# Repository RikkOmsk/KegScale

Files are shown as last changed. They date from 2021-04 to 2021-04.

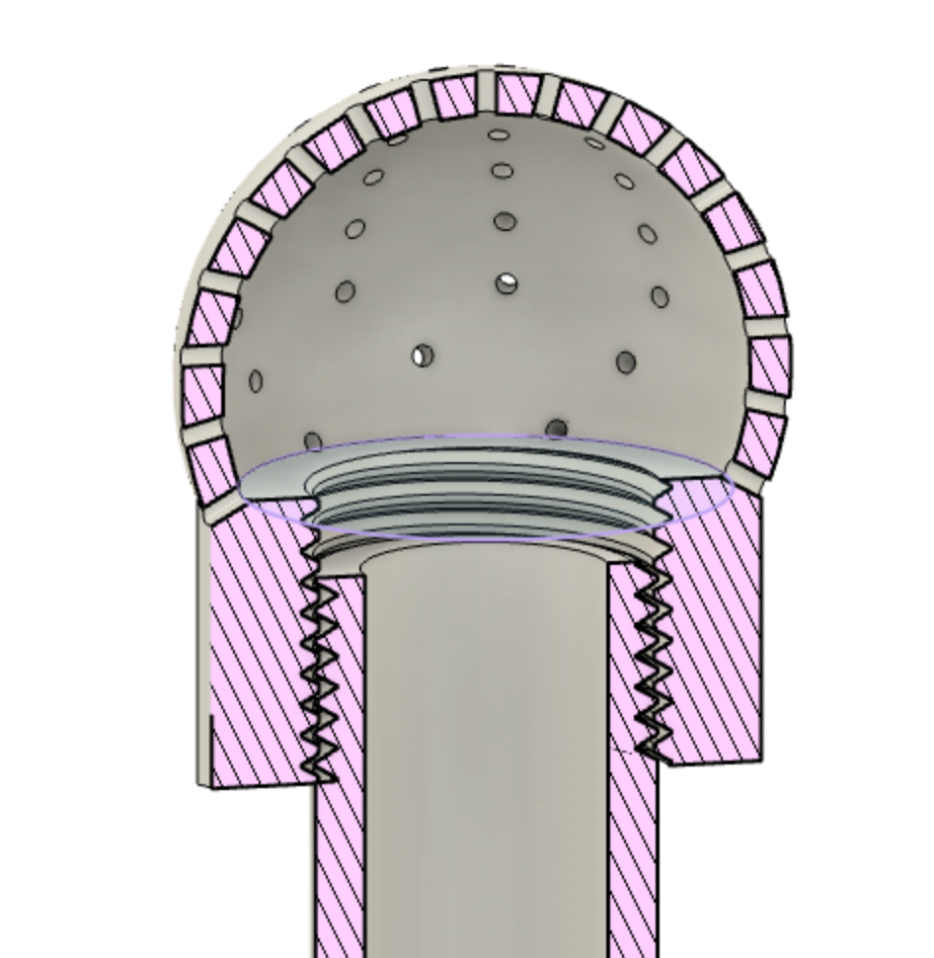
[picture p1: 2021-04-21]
washKeg_0.2/img/screen3.png

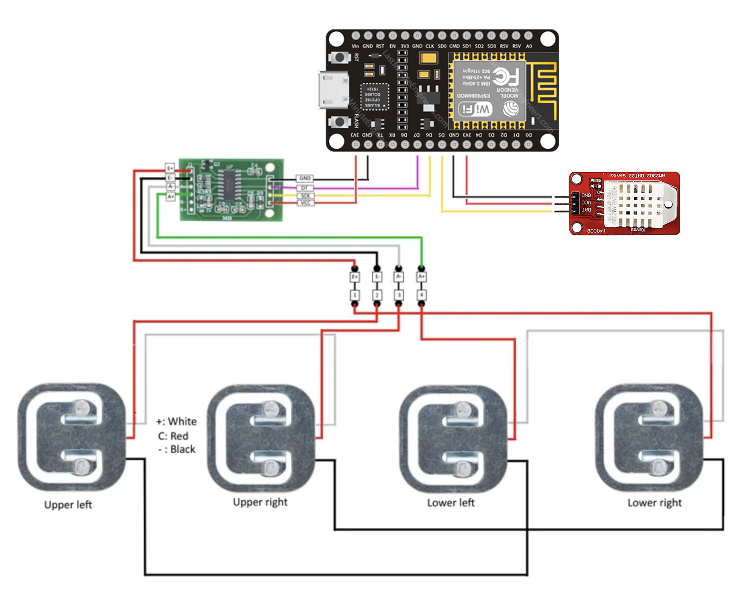
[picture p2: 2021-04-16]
scheme/main.jpg

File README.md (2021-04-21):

# KegScale
Keg Scale

# Железо
Потребуются 
  1. ESP8266        https://aliexpress.ru/item/4000160133215.html
  2. AM2302 DHT22   https://aliexpress.ru/item/32759901711.html
  3. HX711          https://aliexpress.ru/item/1005002176327047.html

# Схема подключения
/scheme/main.jpg

# Прошивка под Arduino
/ESP8266/ESP8266_keg_v02.ino
Необходимо заменить все что под ***
 - auth key blynk
 - ssid wifi
 - pass wifi

# 3D модель для печати
/3dModel/print_01.stl - первая модель площадки. Печать с поддержками 40% заполнения
/3dModel/flexTop v1.stl - первая модель площадки. Флекс резиновое кольцо сверху

/3dModel/print_02.stl - вторая модель площадки
/3dModel/log02_im1.png - список изменений
/3dModel/log02_im2.png - список изменений
/3dModel/log02_im3.png - список изменений

Список изменений v02: 
0. Печататься деталь будет вверх ногами.
1. Сделал паз под провода. Как оказалось, тензодатчики сложно установить без этого паза.
2. Убрал держатели для тензодатчиков. Паз ровно под размер датчиков и встает туда с усилием. Держатели мешали установке детчиков
3. Под NodeMCU дал еще 2 мм прострнаства. Сам ESP находится под смещенем на NodeMCU.
4. Увеличил размеры гнезда под microUSB. Не все штекера подошли.
5. Немного уменьшил вылеты площадки
6. Убрал паз под резиновое кольцо и поменяло форму кольца. Кольцо будет печататься в два слоя сразу же поверх площадки, что сделает изделие аккуратнее, резину тоньше и шире.
7. Сделал более пологий скос, чтобы при печати вверх ногами не потребовались поддержки.

# Калибровка 
Во время отладки необходимо настроить два поля:
int keg1_calibration_factor = -21020;   // Калибровочная значение, индивидуальное для каждой итоговой площадки
int keg1_offset_factor = -64200;        // 0 вес для площадки (сюда вставляем значение, который прилетает в keg1_raw при своем пустом весе)
1. Эти значения будут уникальны для каждого собранно устройства. Начинаем с keg1_offset_factor = в него устанавливаем значение, которое прийдет в keg1_raw при запуске устройства.
2. Далее нужно разместить заранее известный точный вес (например гирю либо бутылку с водой). К примеру вес гири 5кг. Далее мы смотрим на значение в консоли веса, который отображает ваше устройство. Если значение меньше либо больше, то необходимо поправить keg1_calibration_factor в меньшую либо большую сторону и щалитьпрошивку заново. Повторяйте до тех пор пока ваша площадка не будет отображать ровно 5 кг как и гиря.

# Настойка blynk
(будет позже)

# Бонус
washKeg_0.2 - Мойка для кег.
- washKeg_v0.2_top2.stl - 1 шт на кег 10л, вторую накручиваем если кег на 19.
- washKeg_v0.2_top1.stl 2шт.
- washKeg_v0.2_line1.stl 1шт. 
- washKeg_v0.2_line2.stl 2шт.
- washKeg_v0.2_dash.stl 1шт.
- washKeg_v0.2_stat.stl 4шт.

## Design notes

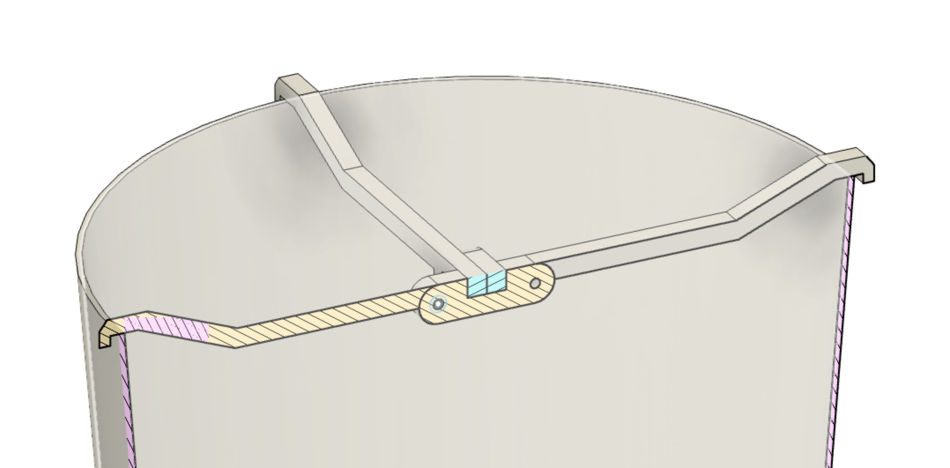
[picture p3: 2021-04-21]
washKeg_0.2/img/screen2.png

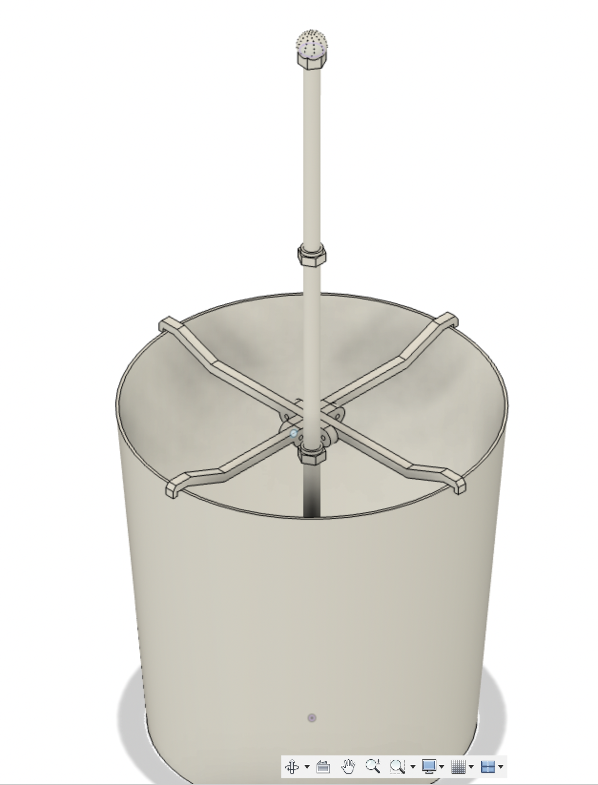
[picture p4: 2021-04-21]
washKeg_0.2/img/screen1.png

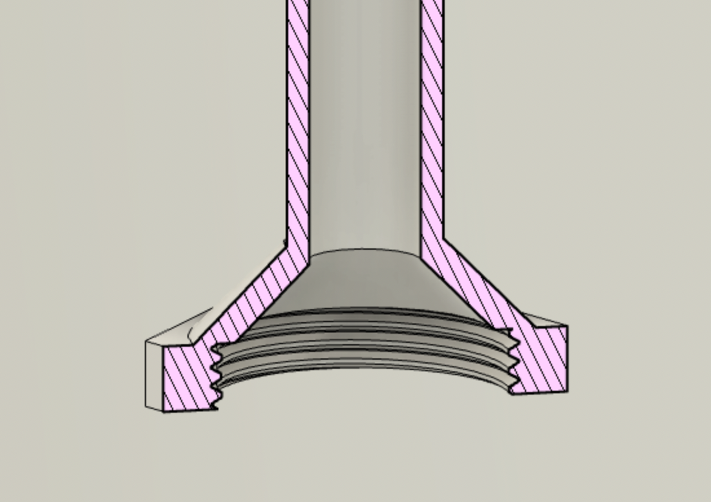
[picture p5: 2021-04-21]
washKeg_0.2/img/screen4.png

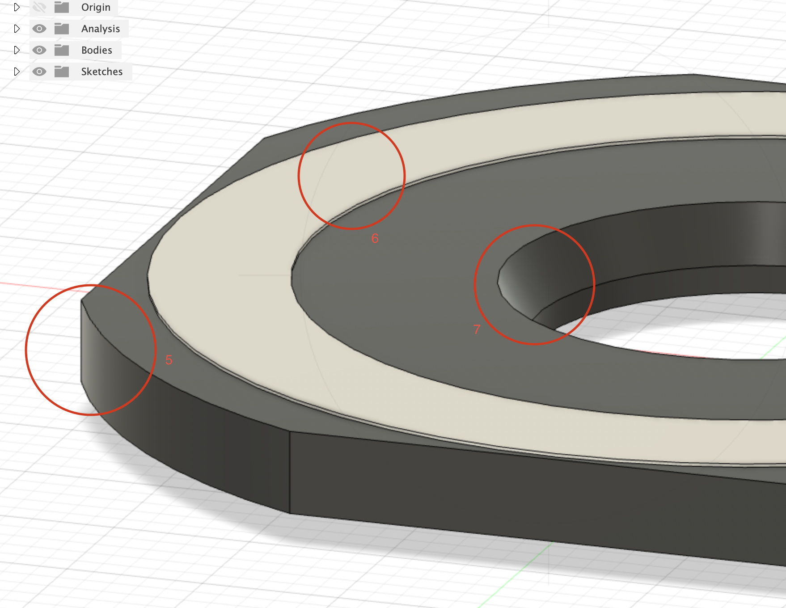
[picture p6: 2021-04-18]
3dModel/log02_im3.png

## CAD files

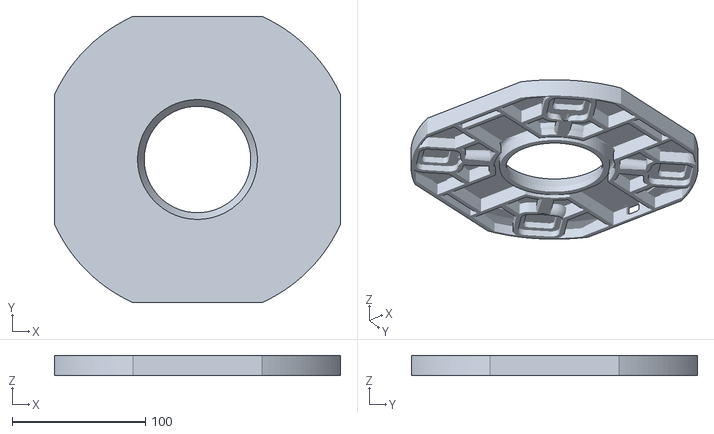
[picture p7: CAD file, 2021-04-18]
3dModel/print_02.stl
215.0 x 215.0 x 15.0

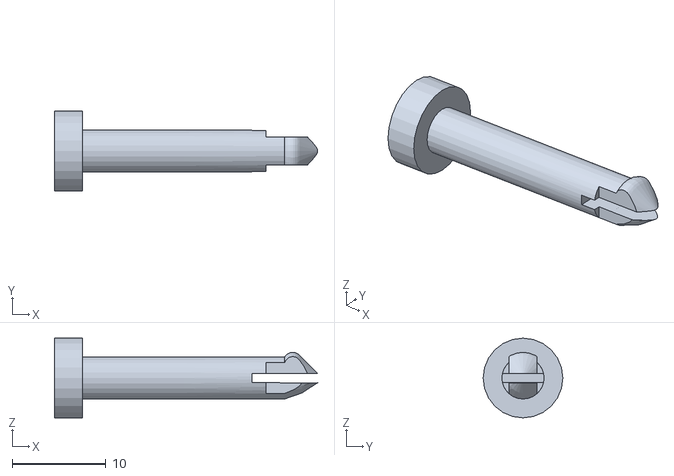
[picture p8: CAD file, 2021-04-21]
washKeg_0.2/model/washKeg_v0.2_stat.stl
28.0 x 8.49 x 8.49

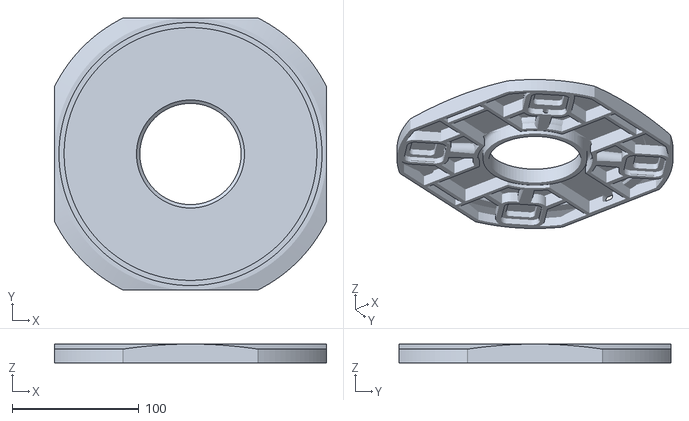
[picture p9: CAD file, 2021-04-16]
3dModel/print_01.stl
215.0 x 215.0 x 15.0

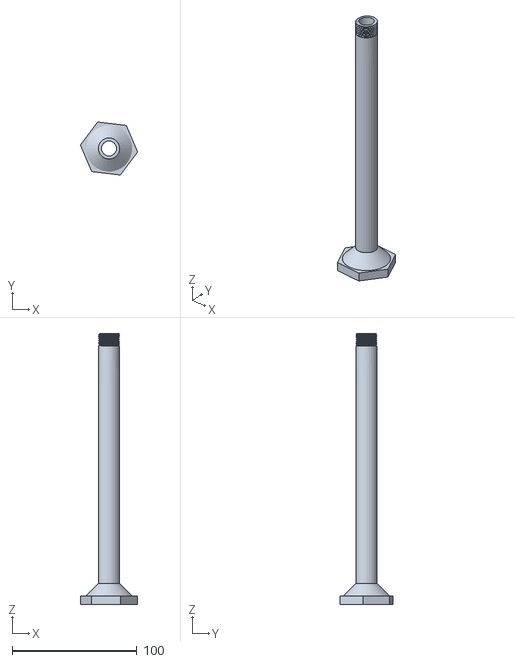
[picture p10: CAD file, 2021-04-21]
washKeg_0.2/model/washKeg_v0.2_line1.stl
45.9 x 42.5 x 217.0

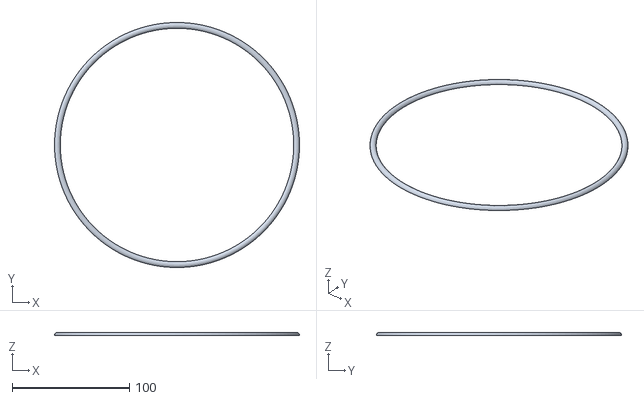
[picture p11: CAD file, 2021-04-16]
3dModel/flexTop v1.stl
208.7 x 208.8 x 2.95

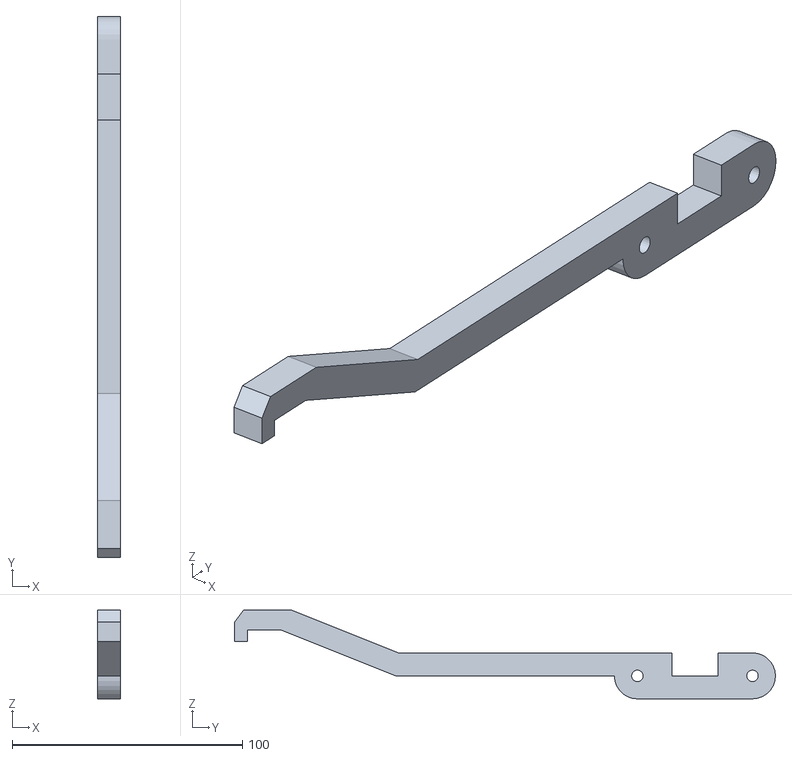
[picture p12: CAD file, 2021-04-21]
washKeg_0.2/model/washKeg_v0.2_top1.stl
10.0 x 235.0 x 38.6

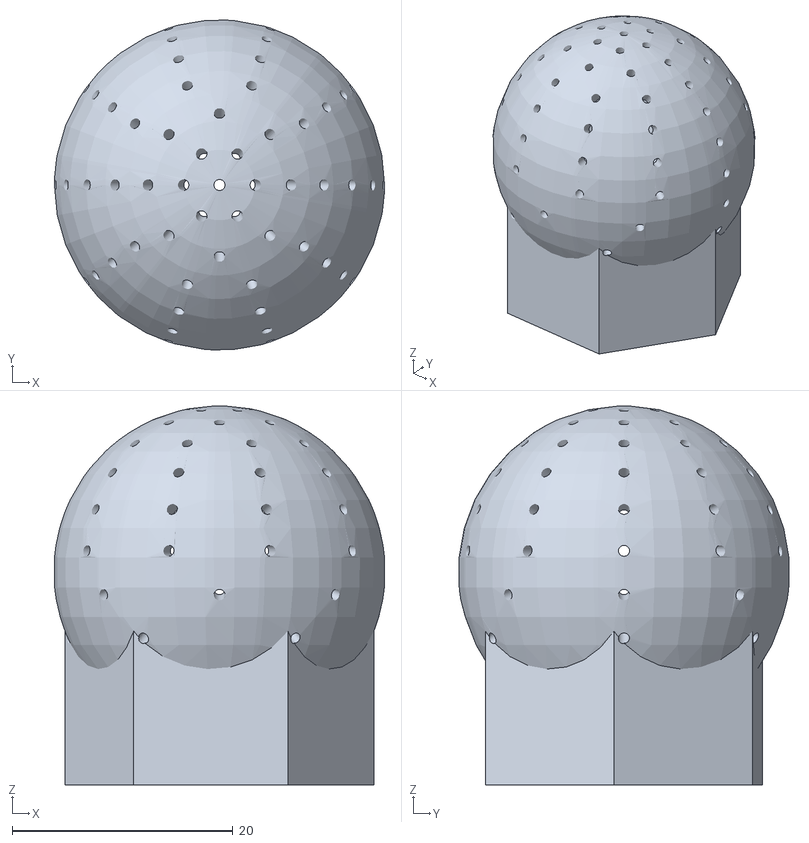
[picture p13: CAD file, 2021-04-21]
washKeg_0.2/model/washKeg_v0.2_dash.stl
29.9 x 29.9 x 34.3

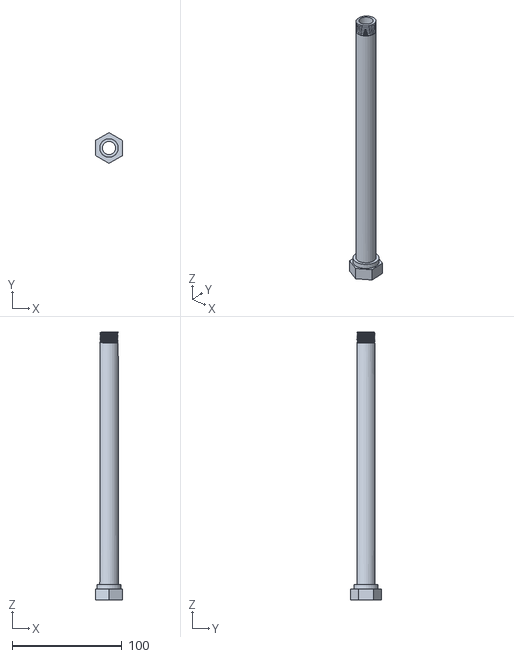
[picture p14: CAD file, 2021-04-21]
washKeg_0.2/model/washKeg_v0.2_line2.stl
24.3 x 28.0 x 244.0

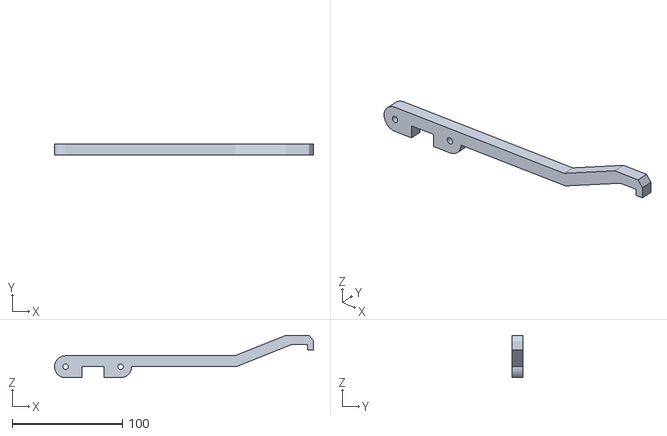
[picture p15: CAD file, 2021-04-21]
washKeg_0.2/model/washKeg_v0.2_top2.stl
235.0 x 10.0 x 38.5

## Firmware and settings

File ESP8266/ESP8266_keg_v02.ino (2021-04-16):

#include <HX711.h>
#include <DHT.h>
#include <DHT_U.h>


#define BLYNK_PRINT Serial
#include <ESP8266WiFi.h>
#include <BlynkSimpleEsp8266.h>


// You should get Auth Token in the Blynk App.
char auth[] = "*******";

// Your WiFi credentials.
char ssid[] = "*****";
char pass[] = "*****";

float beer_coef = 1.04; //1литр пива это 1.04кг

int keg1_calibration_factor = -21020;   // Калибровочная значение, индивидуальное для каждой итоговой площадки
int keg1_offset_factor = -64200;        // 0 вес для площадки (сюда вставляем значение, который прилетает в keg1_raw при своем пустом весе)
float keg1_keg_scale = 0.00;            // Вес пустого кега, размещенного на площадке
bool keg1_isNeedSetKegScale = false;
// Датчик веса
const int keg1_LOADCELL_DOUT_PIN = 13; 
const int keg1_LOADCELL_SCK_PIN = 12;
HX711 keg1_scale;

// датчик DHT
uint8_t DHTPin = D5; 
DHT dht(DHTPin, DHT22);
float temperature;
float humidity;

BlynkTimer timer;


BLYNK_WRITE(V42) { //получаем вес кега 1 с сервера
  float f_scale = param.asFloat();
  if (f_scale > 0){
    keg1_keg_scale = f_scale;
  }else{
    keg1_keg_scale = 0;
  }
}

BLYNK_WRITE(V43){ //получаем состояние кнопки 1 с сервера
  int intButtonPressed = param.asInt();
  if (intButtonPressed == 0) { //нажатие кнопки "сбросить вес" кег1
    Serial.println("Button is pressed.");
    Blynk.setProperty(V43, "label", "Ожидайте");
    keg1_isNeedSetKegScale = true;
  }
}


void myTimerEvent(){

  keg1_scale.power_up();
  float keg1_reading;                       // Значение прочитанное
  float keg1_raw;                           // Сырое значение
  keg1_scale.wait_ready();                  
  keg1_scale.set_scale(keg1_calibration_factor);
  keg1_scale.set_offset(keg1_offset_factor);    

  Serial.print("keg1_Reading: ");
  keg1_scale.wait_ready();
  keg1_reading = keg1_scale.get_units(10); //Read scale in g/Kg
  keg1_raw = keg1_scale.read_average(5);   //Read raw value from scale too
  Serial.print(keg1_reading, 2); Serial.println(" KG");
  Serial.print("keg1_Raw: "); Serial.println(keg1_raw);
  Serial.print("keg1_Calibration factor: "); Serial.println(keg1_calibration_factor);

  float keg1_result;
  if (keg1_isNeedSetKegScale == true){ // если нужно записать вес пустого кега
    keg1_isNeedSetKegScale = false;
    keg1_keg_scale = keg1_reading;
    Blynk.setProperty(V43, "label", "Калибровка кег #1");
  }
  
  keg1_result = (keg1_reading - keg1_keg_scale)/beer_coef;  //(вес итоговый - вес_пустого_кега)/коэф_веса_пива
  Serial.print("keg1_kegScale: ");Serial.print(keg1_keg_scale, 2); Serial.println(" KG");
  Serial.print("keg1_result: ");Serial.print(keg1_result, 2); Serial.println(" L");
  
  if (keg1_result < 0){
     keg1_result = 0.00; //чтобы небыло минусового значения
  }

  Blynk.virtualWrite(V40, keg1_result);
  Blynk.virtualWrite(V41, keg1_raw);
  Blynk.virtualWrite(V42, keg1_keg_scale);
  keg1_scale.power_down();

  

  temperature = dht.readTemperature(); 
  if(!isnan(temperature)){
    Blynk.virtualWrite(V3, temperature);
//    Serial.print("Temperature: ");  Serial.println(temperature);
  }
  
  humidity = dht.readHumidity();
  if(!isnan(humidity)){
    Blynk.virtualWrite(V4, humidity);
//    Serial.print("Humidity: ");  Serial.println(humidity);
  }


}

void setup(){
  Serial.begin(9600);


  keg1_scale.begin(keg1_LOADCELL_DOUT_PIN, keg1_LOADCELL_SCK_PIN); // Start scale on specified pins
  keg1_scale.wait_ready();                               //Ensure scale is ready, this is a blocking function
  keg1_scale.set_scale();
  Serial.println("Scale Set keg1_");
  keg1_scale.wait_ready();
  keg1_scale.tare(); // Tare scale on startup
  keg1_scale.wait_ready();
  Serial.println("Scale Zeroed keg1_");

  
  pinMode(DHTPin, INPUT);
  dht.begin();


  Blynk.begin(auth, ssid, pass); //родной blynk

  
}

BLYNK_CONNECTED() { //как только подключились - запрашиваем значения переменных
    Blynk.syncVirtual(V42);
    Blynk.syncVirtual(V43);
    timer.setInterval(1000L, myTimerEvent);
}

void loop(){
  Blynk.run();
  timer.run();

}
